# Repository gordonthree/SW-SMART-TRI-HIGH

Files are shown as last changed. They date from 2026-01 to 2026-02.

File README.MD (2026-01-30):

# Triple High Side Smart Switch Node

Compact power management board intended to control three high-side DC loads. The node provides current monitoring of each load. Temperature and supply voltage are also monitored. This node works with other CAN-CTL modules using the robust CAN bus interface.

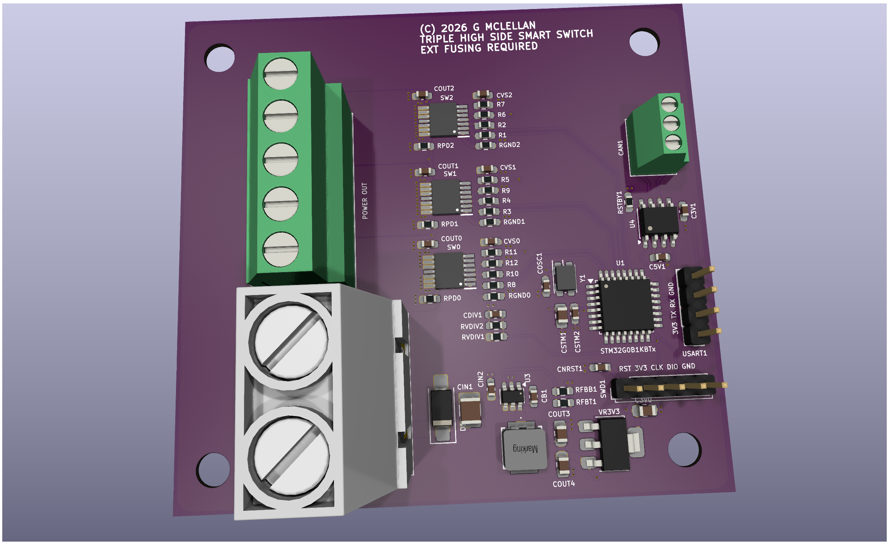
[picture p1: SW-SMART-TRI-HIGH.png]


* STM32G0B1KBTx 32-pin microcontroller
* Three BTS7002 Profet Smart Switches for high side loads, firmware limited to 15 amps each
* Microchip MCP2562 isolated CAN bus transceiver
* Automotive grade 5v switchmode power supply and linear 3.3v regulator
* Voltage divider to monitor supply voltage
* Switch current monitoring and diagnostics
* Three position screw terminal block for CAN bus connection
* Five position screw terminal block for power-out
* Heavy duty terminal block connectors for power in
* Headers for SWD programming and USART1 debug serial port

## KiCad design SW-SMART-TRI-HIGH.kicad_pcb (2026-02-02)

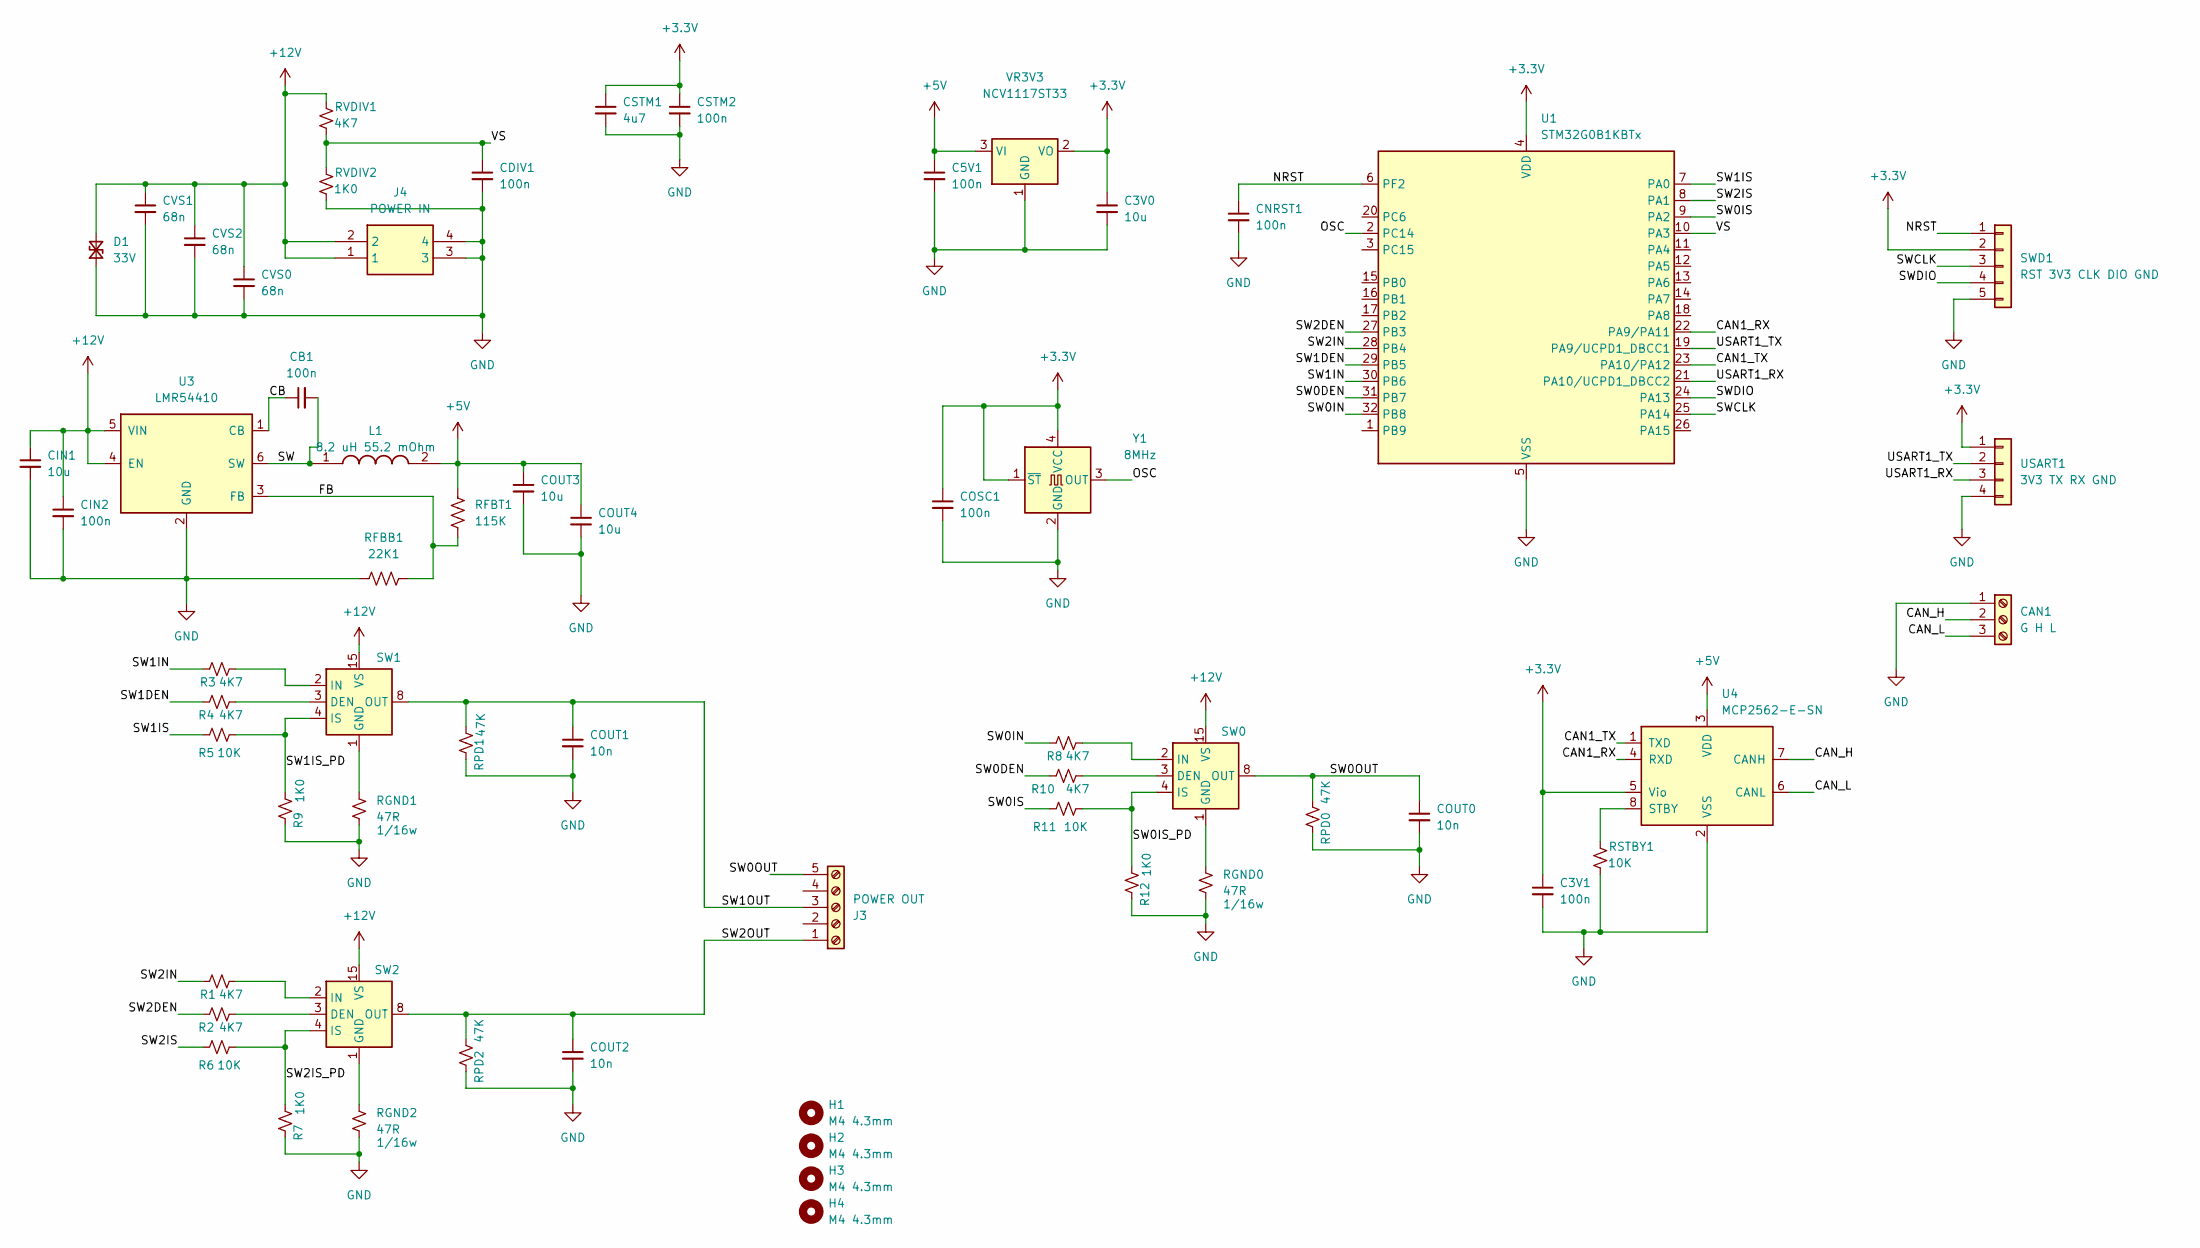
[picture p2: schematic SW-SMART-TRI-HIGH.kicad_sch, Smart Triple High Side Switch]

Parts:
C3V0: 10u; C_0805_2012Metric_Pad1.18x1.45mm_HandSolder
C3V1, C5V1: 100n; C_0603_1608Metric_Pad1.08x0.95mm_HandSolder
CAN1: G H L; TerminalBlock_Phoenix_MPT-0,5-3-2.54_1x03_P2.54mm_Horizontal
CB1: 100n; C_0603_1608Metric_Pad1.08x0.95mm_HandSolder
CDIV1: 100n; C_0603_1608Metric_Pad1.08x0.95mm_HandSolder
CIN1: 10u; C_1210_3225Metric_Pad1.33x2.70mm_HandSolder
CIN2: 100n; C_0603_1608Metric_Pad1.08x0.95mm_HandSolder
CNRST1: 100n; C_0603_1608Metric_Pad1.08x0.95mm_HandSolder
COSC1: 100n; C_0603_1608Metric_Pad1.08x0.95mm_HandSolder
COUT0, COUT1, COUT2: 10n; C_0603_1608Metric_Pad1.08x0.95mm_HandSolder
COUT3, COUT4: 10u; C_0805_2012Metric_Pad1.18x1.45mm_HandSolder
CSTM1: 4u7; C_0805_2012Metric_Pad1.18x1.45mm_HandSolder
CSTM2: 100n; C_0603_1608Metric_Pad1.08x0.95mm_HandSolder
CVS0, CVS1, CVS2: 68n; C_0603_1608Metric_Pad1.08x0.95mm_HandSolder
D1: 33V; D_SMA_Handsoldering
H1, H2, H3, H4: M4 4.3mm; MountingHole_4.3mm_M4
J3: POWER OUT; TerminalBlock_Phoenix_MKDS-3-5-5.08_1x05_P5.08mm_Horizontal
J4: POWER IN; VP0265840000G; Mouser Part Number 649-VP02658400J0G
L1: 8.2 uH 55.2 mOhm; SRP5030HMT2R2M; Mouser Part Number SRP5030HMT-8R2M
R1, R2, R3, R4, R8, R10: 4K7; R_0603_1608Metric_Pad0.98x0.95mm_HandSolder
R5, R6, R11: 10K; R_0603_1608Metric_Pad0.98x0.95mm_HandSolder
R7, R9, R12: 1K0; R_0603_1608Metric_Pad0.98x0.95mm_HandSolder
RFBB1: 22K1; R_0603_1608Metric_Pad0.98x0.95mm_HandSolder
RFBT1: 115K; R_0603_1608Metric_Pad0.98x0.95mm_HandSolder
RGND0, RGND1, RGND2: 47R; R_0603_1608Metric_Pad0.98x0.95mm_HandSolder
RPD0, RPD1, RPD2: 47K; R_0603_1608Metric_Pad0.98x0.95mm_HandSolder
RSTBY1: 10K; R_0603_1608Metric_Pad0.98x0.95mm_HandSolder
RVDIV1: 4K7; R_0603_1608Metric_Pad0.98x0.95mm_HandSolder
RVDIV2: 1K0; R_0603_1608Metric_Pad0.98x0.95mm_HandSolder
SW0, SW1, SW2: BTS7002-1EPP; SOP65P600X115-15N
SWD1: RST 3V3 CLK DIO GND; PinHeader_1x05_P2.54mm_Vertical
U1: STM32G0B1KBTx; LQFP-32_7x7mm_P0.8mm
U3: LMR54410; SOT-23-6
U4: MCP2562-E-SN; SOIC-8_3.9x4.9mm_P1.27mm
USART1: 3V3 TX RX GND; PinHeader_1x04_P2.54mm_Vertical
VR3V3: NCV1117ST33; SOT-223-3_TabPin2
Y1: 8MHz; Oscillator_SMD_XO-4Pin_3.2x2.5mm_HandSoldering

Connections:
+3.3V: C3V0.1, C3V1.1, COSC1.1, CSTM1.1, CSTM2.1, SWD1.2, U1.4 (VDD), U4.5 (Vio), USART1.1, VR3V3.2 (VO), Y1.1 (~ST), Y1.4 (VCC)
+5V: C5V1.1, COUT3.1, COUT4.1, L1.2, RFBT1.1, U4.3 (VDD), VR3V3.3 (VI)
+12V: CIN1.1, CIN2.1, CVS0.1, CVS1.1, CVS2.1, D1.2 (A2), J4.1, J4.2, RVDIV1.2, SW0.15 (VS), SW1.15 (VS), SW2.15 (VS), U3.4 (EN), U3.5 (VIN)
/CAN1_RX: U1.22 (PA9/PA11), U4.4 (RXD)
/CAN1_TX: U1.23 (PA10/PA12), U4.1 (TXD)
/CAN_H: CAN1.2, U4.7 (CANH)
/CAN_L: CAN1.3, U4.6 (CANL)
/CB: CB1.1, U3.1 (CB)
/FB: RFBB1.2, RFBT1.2, U3.3 (FB)
/NRST: CNRST1.1, SWD1.1, U1.6 (PF2)
/OSC: U1.2 (PC14), Y1.3 (OUT)
/SW: CB1.2, L1.1, U3.6 (SW)
/SW0DEN: R10.1, U1.31 (PB7)
/SW0IN: R8.1, U1.32 (PB8)
/SW0IS: R11.1, U1.9 (PA2)
/SW0IS_PD: R11.2, R12.2, SW0.4 (IS)
/SW0OUT: COUT0.1, J3.5, RPD0.2, SW0.8 (OUT), SW0.9 (OUT), SW0.10 (OUT), SW0.12 (OUT), SW0.13 (OUT), SW0.14 (OUT)
/SW1DEN: R4.1, U1.29 (PB5)
/SW1IN: R3.1, U1.30 (PB6)
/SW1IS: R5.1, U1.7 (PA0)
/SW1IS_PD: R5.2, R9.2, SW1.4 (IS)
/SW1OUT: COUT1.1, J3.3, RPD1.2, SW1.8 (OUT), SW1.9 (OUT), SW1.10 (OUT), SW1.12 (OUT), SW1.13 (OUT), SW1.14 (OUT)
/SW2DEN: R2.1, U1.27 (PB3)
/SW2IN: R1.1, U1.28 (PB4)
/SW2IS: R6.1, U1.8 (PA1)
/SW2IS_PD: R6.2, R7.2, SW2.4 (IS)
/SW2OUT: COUT2.1, J3.1, RPD2.2, SW2.8 (OUT), SW2.9 (OUT), SW2.10 (OUT), SW2.12 (OUT), SW2.13 (OUT), SW2.14 (OUT)
/SWCLK: SWD1.3, U1.25 (PA14)
/SWDIO: SWD1.4, U1.24 (PA13)
/USART1_RX: U1.21 (PA10/UCPD1_DBCC2), USART1.3
/USART1_TX: U1.19 (PA9/UCPD1_DBCC1), USART1.2
/VS: CDIV1.1, RVDIV1.1, RVDIV2.2, U1.10 (PA3)
GND: C3V0.2, C3V1.2, C5V1.2, CAN1.1, CDIV1.2, CIN1.2, CIN2.2, CNRST1.2, COSC1.2, COUT0.2, COUT1.2, COUT2.2, COUT3.2, COUT4.2, CSTM1.2, CSTM2.2, CVS0.2, CVS1.2, CVS2.2, D1.1 (A1), J4.3, J4.4, R7.1, R9.1, R12.1, RFBB1.1, RGND0.2, RGND1.2, RGND2.2, RPD0.1, RPD1.1, RPD2.1, RSTBY1.1, RVDIV2.1, SWD1.5, U1.5 (VSS), U3.2 (GND), U4.2 (VSS), USART1.4, VR3V3.1 (GND), Y1.2 (GND)
unnamed: R10.2, SW0.3 (DEN)
unnamed: RGND0.1, SW0.1 (GND)
unnamed: R8.2, SW0.2 (IN)
unnamed: R4.2, SW1.3 (DEN)
unnamed: RGND1.1, SW1.1 (GND)
unnamed: R3.2, SW1.2 (IN)
unnamed: R2.2, SW2.3 (DEN)
unnamed: RGND2.1, SW2.1 (GND)
unnamed: R1.2, SW2.2 (IN)
unnamed: RSTBY1.2, U4.8 (STBY)

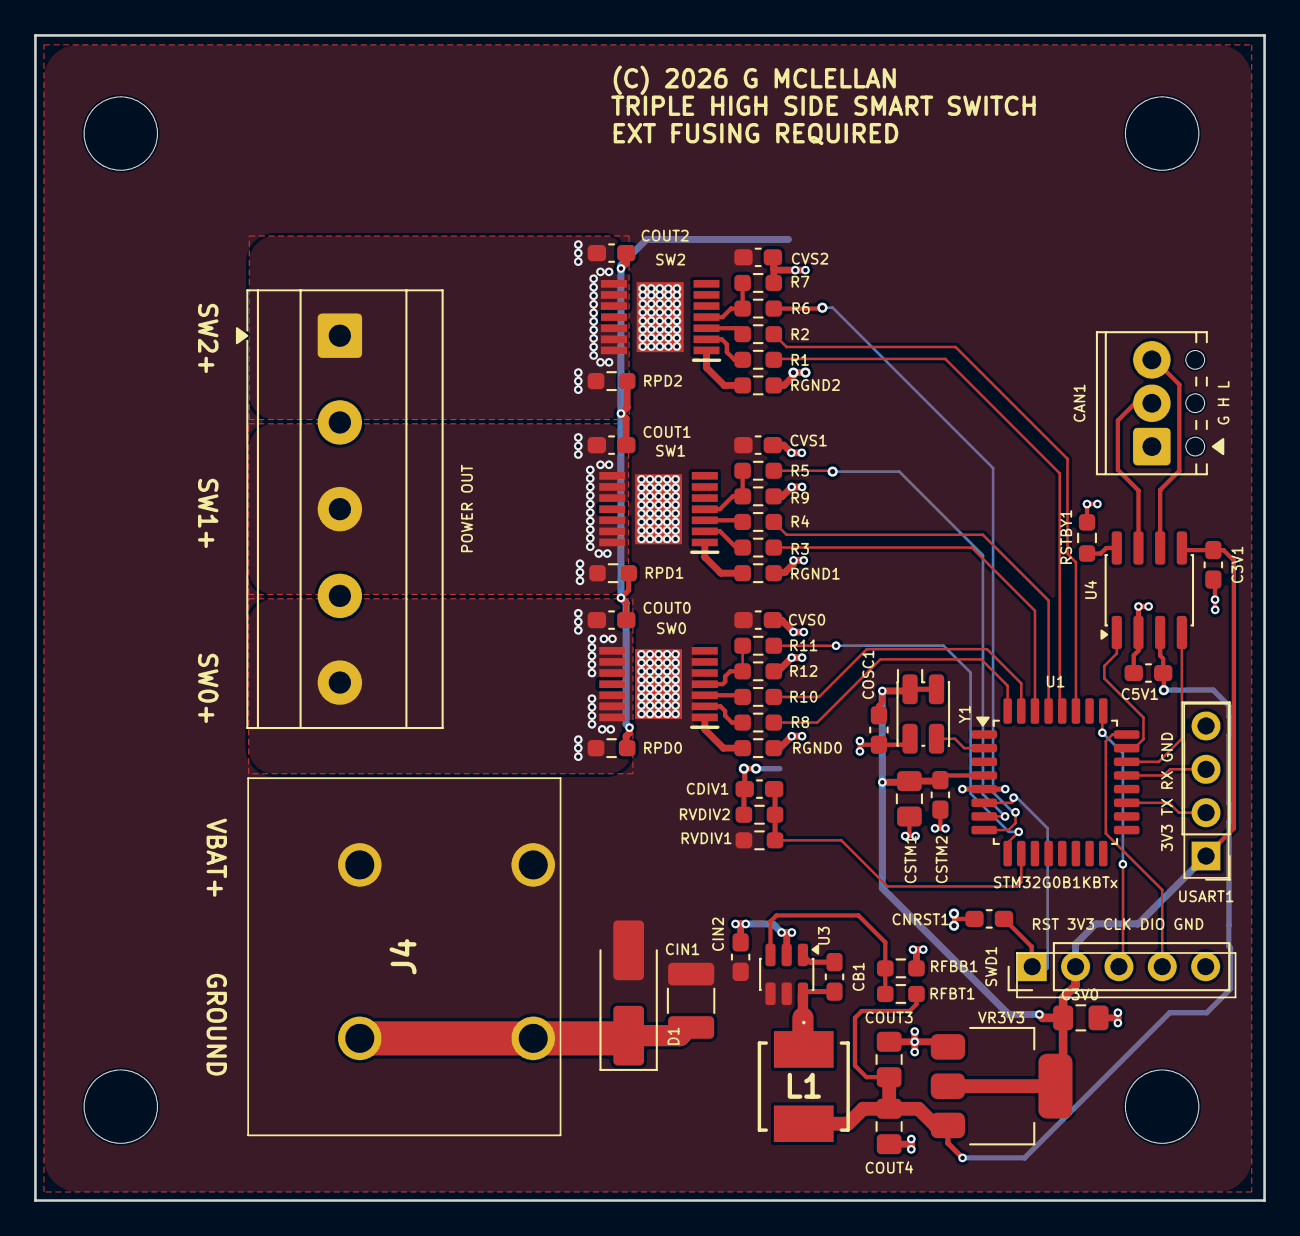
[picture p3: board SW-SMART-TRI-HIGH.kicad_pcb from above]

Board: 2 copper layers, 72.0 x 68.2 mm, 61 parts (0 on the bottom side), 43 nets.

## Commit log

2026-01-20 schematic and layout mostly complete
    [SW-SMART-TRI-HIGH.kicad_pcb, SW-SMART-TRI-HIGH.kicad_sch]
2026-01-20 fattened up some tracks
    [SW-SMART-TRI-HIGH.kicad_pcb]
2026-01-20 renamed power in connector
    [SW-SMART-TRI-HIGH.kicad_sch]
2026-01-26 switch to smps for 5v, adjust CAN and SWD pin connections
    [SW-SMART-TRI-HIGH.kicad_pcb, SW-SMART-TRI-HIGH.kicad_sch]
2026-01-26 improve ground connections, cleanup silkscreen
    [SW-SMART-TRI-HIGH.kicad_pcb, SW-SMART-TRI-HIGH.kicad_sch]
2026-01-30 fixed some footprints, made the +12v pour a bit bigger on the bottom side
    [SW-SMART-TRI-HIGH.kicad_pcb]
2026-01-30 updated rendering to include 5v SMPS
2026-02-02 add 8mhz XO, fix some footprint issues
    [SW-SMART-TRI-HIGH.kicad_pcb, SW-SMART-TRI-HIGH.kicad_sch]

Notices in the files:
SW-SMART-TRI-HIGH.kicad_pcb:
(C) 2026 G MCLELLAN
